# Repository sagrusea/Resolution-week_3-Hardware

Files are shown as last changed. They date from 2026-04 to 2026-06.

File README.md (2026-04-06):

# Resolution-week_3-Hardware
A cross made up of 16 leds with another 4 leds, one for each corner. I made this becouse i wanted to use the cd4020 and lm556 for the first time, and also create a good looking circuit.

#### Render:
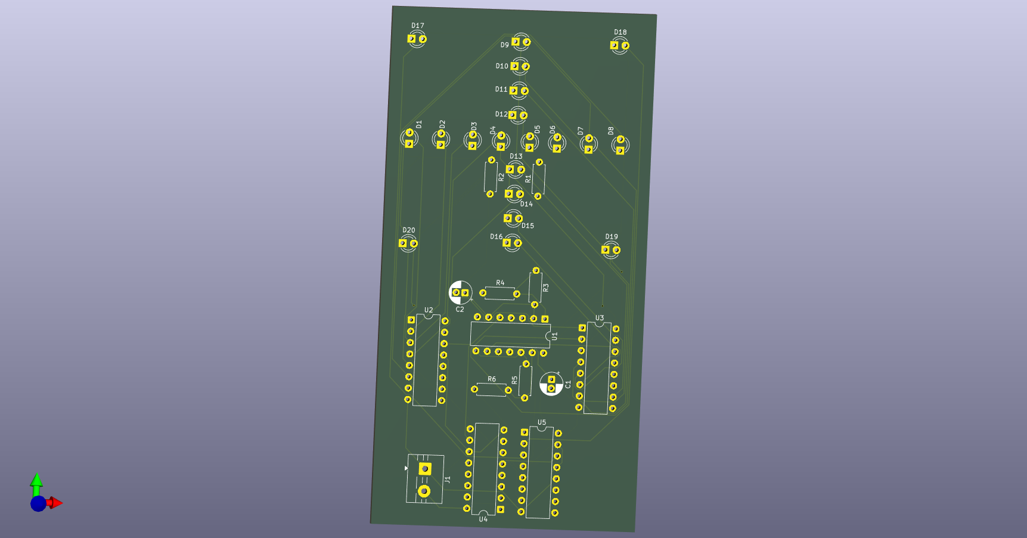
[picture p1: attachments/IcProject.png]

#### Schematic:
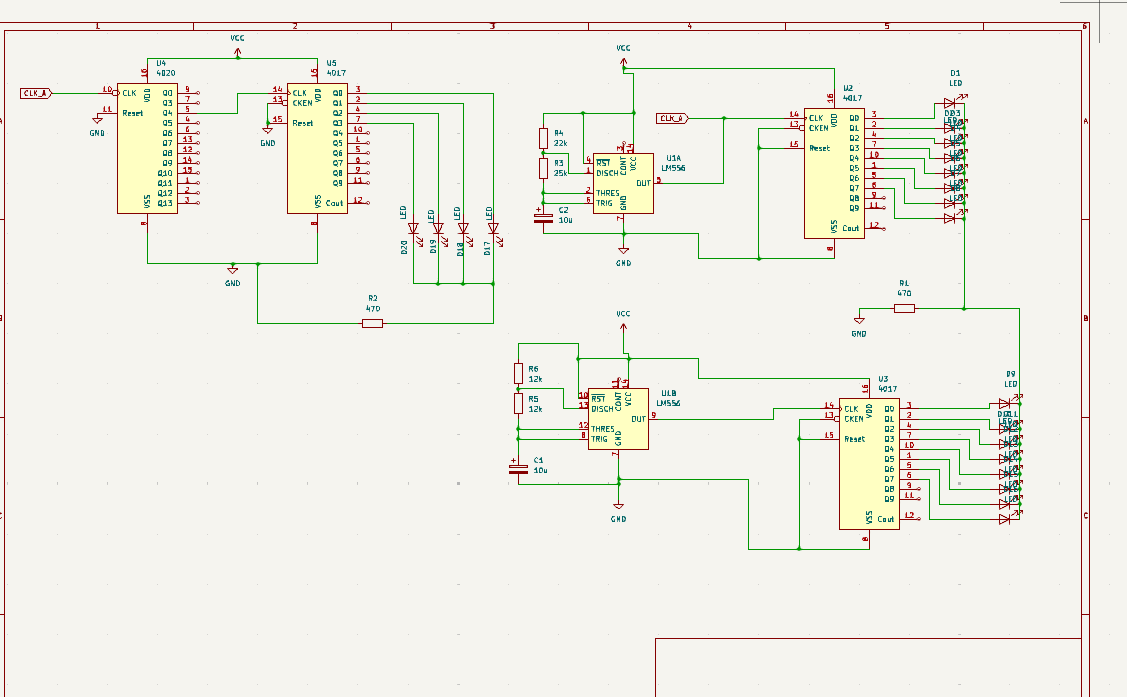
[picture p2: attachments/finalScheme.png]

#### KiCanvas:  
<a href="https://kicanvas.org/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">link</a>

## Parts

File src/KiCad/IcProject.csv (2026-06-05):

Reference | Qty | Value | DNP | Exclude from BOM | Exclude from Board | Footprint | Datasheet
C1,C2 | 2 | 10u |  |  |  | Capacitor_THT:CP_Radial_D5.0mm_P2.00mm
D1,D2,D3,D4,D5,D6,D7,D8,D9,D10,D11,D12,D13,D14,D15,D16 | 16 | LED |  |  |  | LED_THT:LED_D3.0mm
D17,D18,D19,D20 | 4 | Blue |  |  |  | LED_THT:LED_D3.0mm
J1 | 1 | Screw_Terminal_01x02 |  |  |  | TerminalBlock:TerminalBlock_MaiXu_MX126-5.0-02P_1x02_P5.00mm
R1 | 1 | 470 |  |  |  | Resistor_THT:R_Axial_DIN0207_L6.3mm_D2.5mm_P7.62mm_Horizontal
R2 | 1 | 220 |  |  |  | Resistor_THT:R_Axial_DIN0207_L6.3mm_D2.5mm_P7.62mm_Horizontal
R3 | 1 | 25k |  |  |  | Resistor_THT:R_Axial_DIN0207_L6.3mm_D2.5mm_P7.62mm_Horizontal
R4 | 1 | 22k |  |  |  | Resistor_THT:R_Axial_DIN0207_L6.3mm_D2.5mm_P7.62mm_Horizontal
R5,R6 | 2 | 12k |  |  |  | Resistor_THT:R_Axial_DIN0207_L6.3mm_D2.5mm_P7.62mm_Horizontal
U1 | 1 | LM556 |  |  |  | Package_DIP:DIP-14_W7.62mm | https://www.mouser.com/datasheet/2/405/lm556-405954.pdf
U2,U3,U5 | 3 | 4017 |  |  |  | Package_DIP:DIP-16_W7.62mm | http://www.intersil.com/content/dam/Intersil/documents/cd40/cd4017bms-22bms.pdf
U4 | 1 | 4020 |  |  |  | Package_DIP:DIP-16_W7.62mm | http://www.intersil.com/content/dam/Intersil/documents/cd40/cd4020bms-24bms-40bms.pdf

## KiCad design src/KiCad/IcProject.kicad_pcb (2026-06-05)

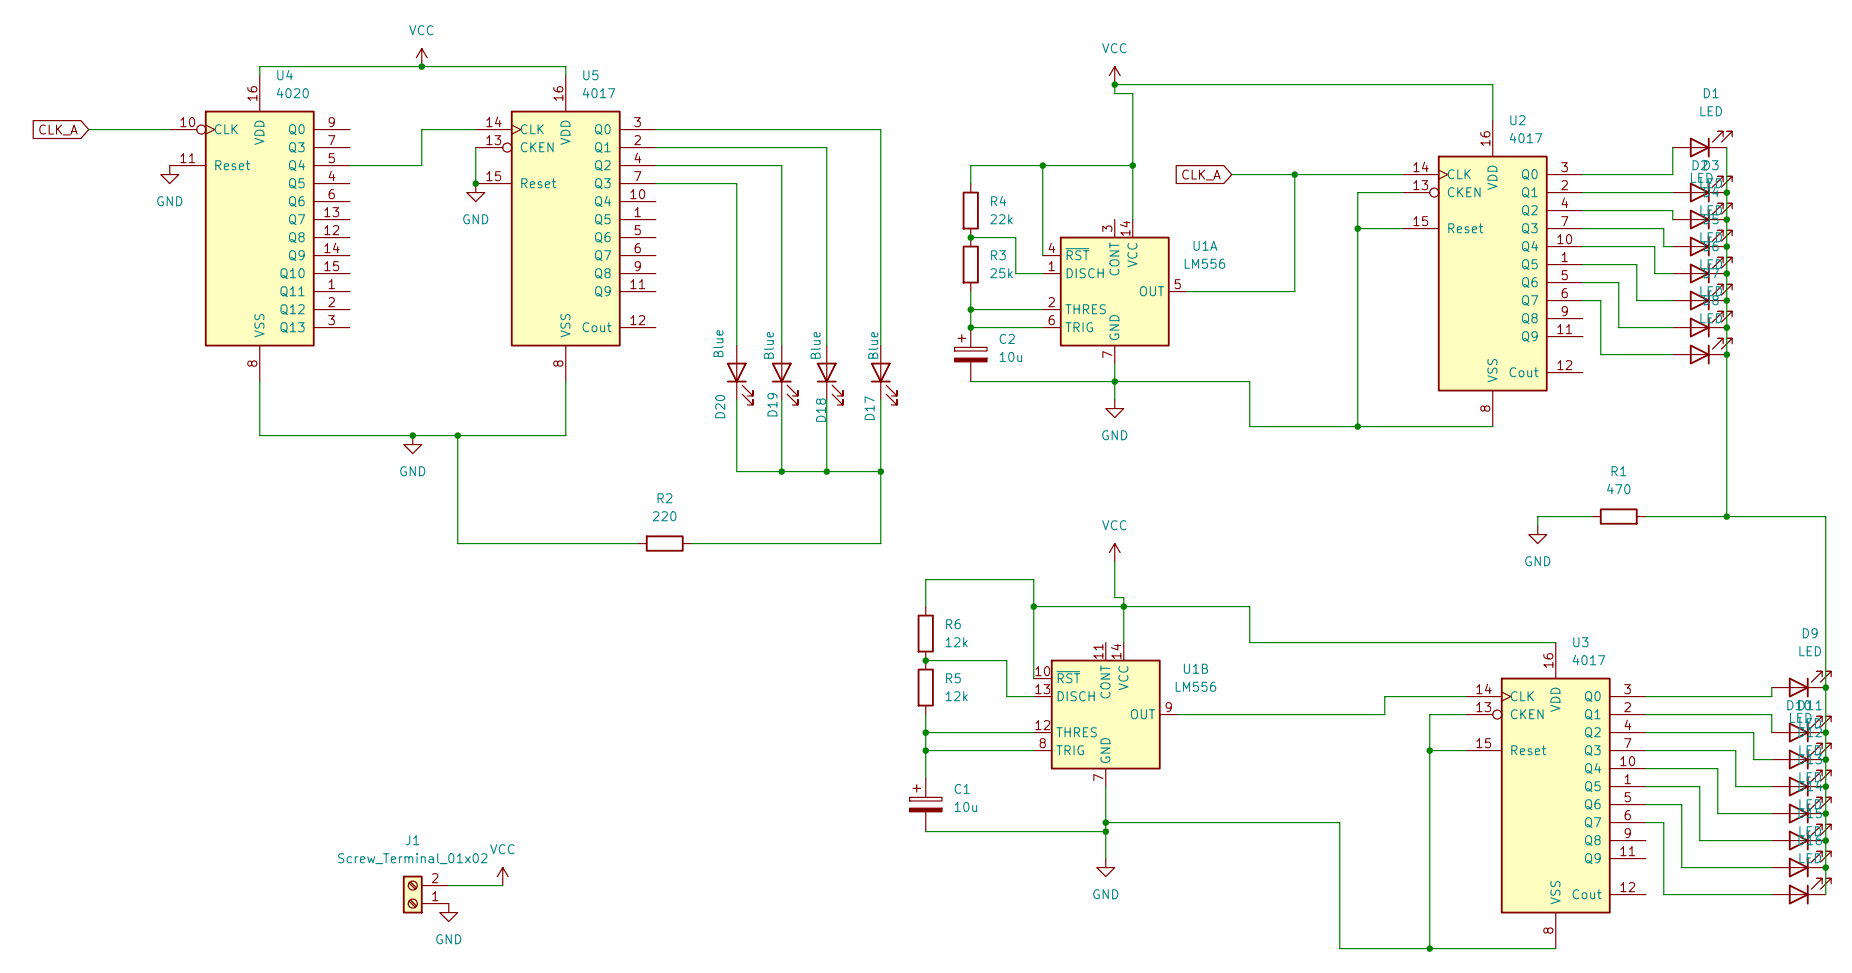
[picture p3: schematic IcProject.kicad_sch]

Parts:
C1, C2: 10u; CP_Radial_D5.0mm_P2.00mm
D1, D2, D3, D4, D5, D6, D7, D8, D9, D10, D11, D12, D13, D14, D15, D16: LED; LED_D3.0mm
D17, D18, D19, D20: Blue; LED_D3.0mm
J1: Screw_Terminal_01x02; TerminalBlock_MaiXu_MX126-5.0-02P_1x02_P5.00mm
R1: 470; R_Axial_DIN0207_L6.3mm_D2.5mm_P7.62mm_Horizontal
R2: 220; R_Axial_DIN0207_L6.3mm_D2.5mm_P7.62mm_Horizontal
R3: 25k; R_Axial_DIN0207_L6.3mm_D2.5mm_P7.62mm_Horizontal
R4: 22k; R_Axial_DIN0207_L6.3mm_D2.5mm_P7.62mm_Horizontal
R5, R6: 12k; R_Axial_DIN0207_L6.3mm_D2.5mm_P7.62mm_Horizontal
U1: LM556; DIP-14_W7.62mm
U2, U3, U5: 4017; DIP-16_W7.62mm
U4: 4020; DIP-16_W7.62mm

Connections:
CLK_A: U1.5 (OUT), U2.14 (CLK), U4.10 (CLK)
GND: C1.2, C2.2, J1.1, R1.1, R2.2, U1.7 (GND), U2.8 (VSS), U2.13 (CKEN), U2.15 (Reset), U3.8 (VSS), U3.13 (CKEN), U3.15 (Reset), U4.8 (VSS), U4.11 (Reset), U5.8 (VSS), U5.13 (CKEN), U5.15 (Reset)
unnamed: D1.2 (A), U2.3 (Q0)
unnamed: D1.1 (K), D2.1 (K), D3.1 (K), D4.1 (K), D5.1 (K), D6.1 (K), D7.1 (K), D8.1 (K), D9.1 (K), D10.1 (K), D11.1 (K), D12.1 (K), D13.1 (K), D14.1 (K), D15.1 (K), D16.1 (K), R1.2
unnamed: D2.2 (A), U2.2 (Q1)
unnamed: D3.2 (A), U2.4 (Q2)
unnamed: D4.2 (A), U2.7 (Q3)
unnamed: D5.2 (A), U2.10 (Q4)
unnamed: D6.2 (A), U2.1 (Q5)
unnamed: D7.2 (A), U2.5 (Q6)
unnamed: D8.2 (A), U2.6 (Q7)
unnamed: D9.2 (A), U3.3 (Q0)
unnamed: D10.2 (A), U3.2 (Q1)
unnamed: D11.2 (A), U3.4 (Q2)
unnamed: D12.2 (A), U3.7 (Q3)
unnamed: D13.2 (A), U3.10 (Q4)
unnamed: D14.2 (A), U3.1 (Q5)
unnamed: D15.2 (A), U3.5 (Q6)
unnamed: D16.2 (A), U3.6 (Q7)
unnamed: D17.2 (A), U5.3 (Q0)
unnamed: D17.1 (K), D18.1 (K), D19.1 (K), D20.1 (K), R2.1
unnamed: D18.2 (A), U5.2 (Q1)
unnamed: D19.2 (A), U5.4 (Q2)
unnamed: D20.2 (A), U5.7 (Q3)
unnamed: R3.1, R4.2, U1.1 (DISCH)
unnamed: C2.1, R3.2, U1.2 (THRES), U1.6 (TRIG)
unnamed: R5.1, R6.2, U1.13 (DISCH)
unnamed: U1.9 (OUT), U3.14 (CLK)
unnamed: C1.1, R5.2, U1.8 (TRIG), U1.12 (THRES)
unnamed: U4.5 (Q4), U5.14 (CLK)
VCC: J1.2, R4.1, R6.1, U1.4 (~RST), U1.10 (~RST), U1.14 (VCC), U2.16 (VDD), U3.16 (VDD), U4.16 (VDD), U5.16 (VDD)

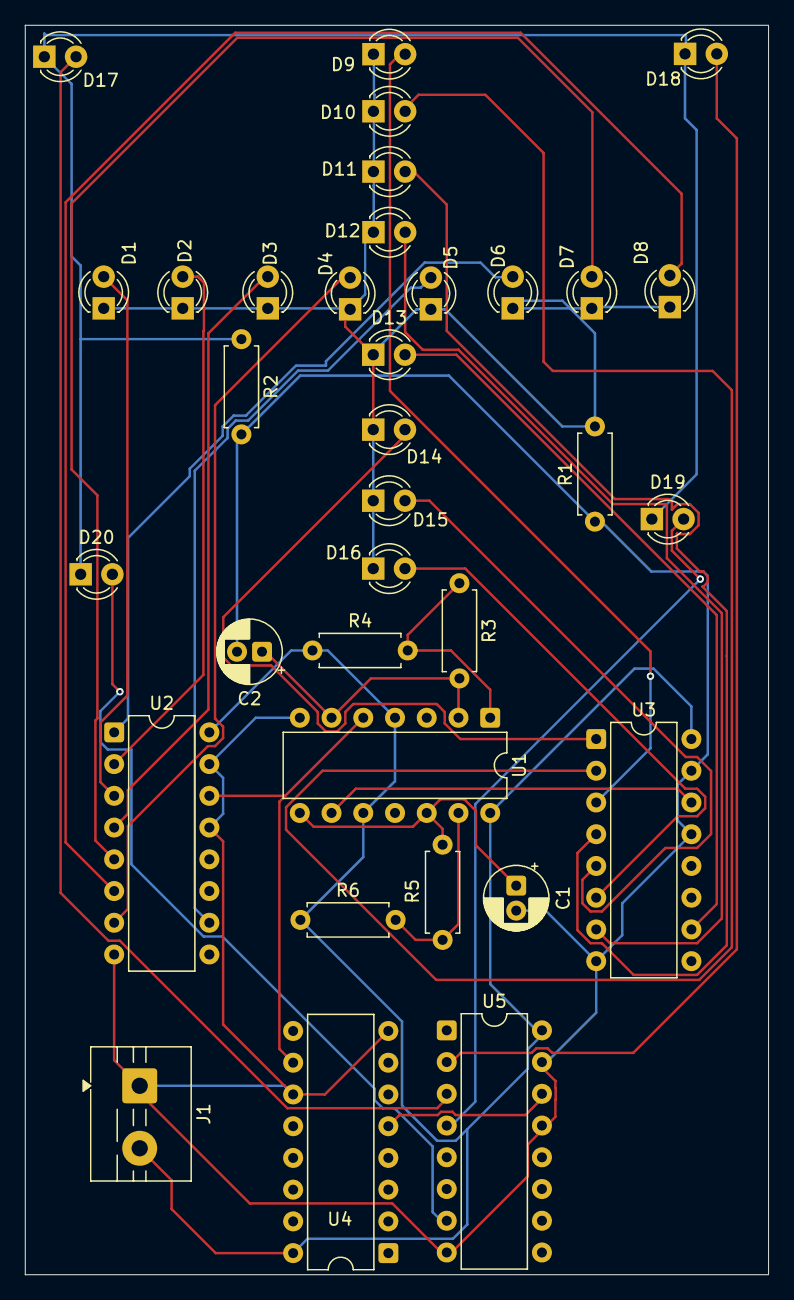
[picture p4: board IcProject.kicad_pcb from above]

Board: 2 copper layers, 59.5 x 100.0 mm, 34 parts (0 on the bottom side), 31 nets.

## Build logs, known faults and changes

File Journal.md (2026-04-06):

## 1.4.2026
### Time spent: 1h
i wanted to make a row of leds going from 1 to x and from x to 1 and going at varying speeds that the ics would dictate. My first step was to try and simulate the ics in a software of some sort, well i spent an hour trying to get multiple diffrent simulators working. I tried to do it in falstad which would actually be possible but way too much work, so i tried the next best thing i could think of, kicad spice simulation. I tried to look up spice models of the cd4020 and cd4017 but i wasnt succesfull. So i tried asking ai to give me the spice models and yet again nothing, i did a lot of debugging since kicad always spat a lot of errors at me, i didnt understand a single error, after an hour i gave up..

## 2.4.2026
### Time spent: 20 mins
I scrapped my old idea and started working on a completly new one.Firstly i looked up what the lm556 is and how i could use it, its basically 2 ne555s in one package, so i based my idea on 2 main frequencies. A crosshair of 8 (16 total) Leds + 4 leds in the corners, with frequencies as in the image. Since we have the main part i picked 2 cd4017 to drive the 16 leds i didnt have to research anything since i used it before. I will also most likely use a cd4020 for frequency C, and i will most likely change the frequencies(probably b and c so the cd4020 can handle tha math)  

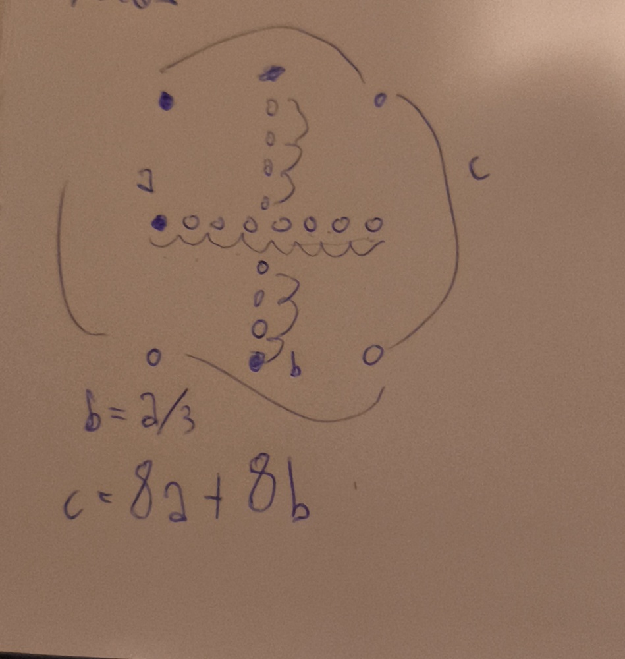
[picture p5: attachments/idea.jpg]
idea
  

> So far i have put the lm556 inside my kicad schematic, but its weird it is 2 symbols with either unit a or b markings. I also imported the cd4017 for both parts(a + b), and wired up the gnds and vccs, and outputs of both parts to their own cd4017  

## 2.4.2026 #2
### Time spent: 30 mins
I wired up the 2 cd4017s to the leds, and their reset and clk enable pins to GND. I connected the cathodes of the 16 leds to ground through a resistor(i will calculate the value later). I also added a cd4020 and another cd4017 to the schematic and wired the reset pins of both Ics to GND, and added a label for clock A and put the label to Lm556s part A and cd4020 clk so they are connected, i will need to do math to figure out the correct speed. Now a big thing i need to decide if i want the leds of the crosshair to go d1-d2........d8-d7-d6....  , or not. If i would choose the first option i would need to either lower the amount of leds to 6 so i could use the existing cd4017 or use an extra cd4017 but i dont think that would be efficient enough idk tho. That decision is for after i wake up since its a bit past midnight already.
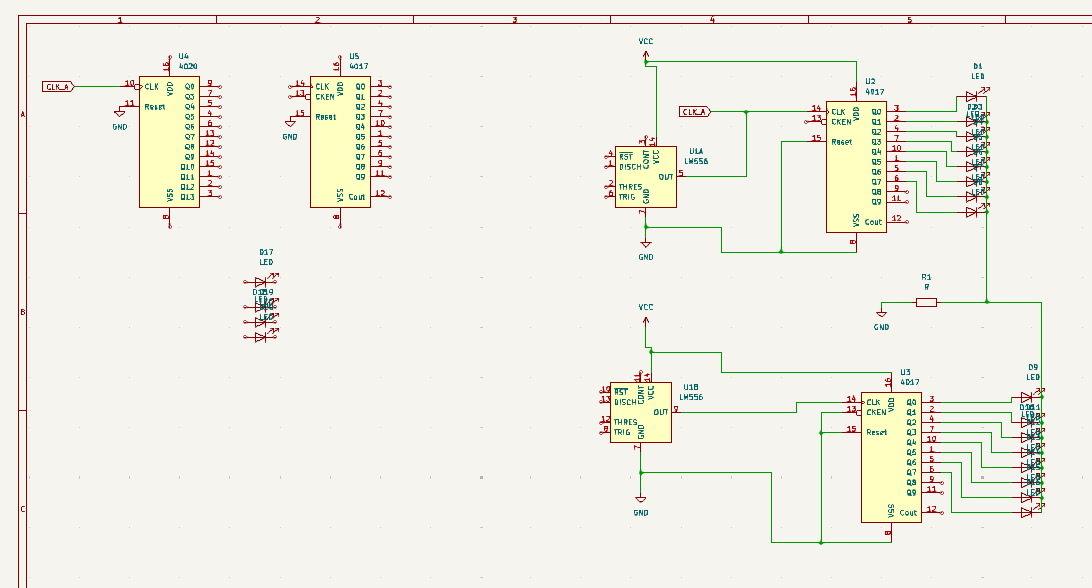
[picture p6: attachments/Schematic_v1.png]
  

## 6.4.2026
### Time spent: 1H 40 mins
From last time a lot changed i reworked the frequencies so frequencies ended up like this a = 2 Hz b = 4 Hz and c = a/8.  
> so c = 0.25Hz  

Than i used a NE555 calculator in astable configuration and calculated what resistors and capacitors i need for the frequencies a and b. I also decided that the 4 LEDs that are driven by frequency c will be blue so it has a nice contrast. Once i had my new version in mind i put all of the resistors in the config that the digikey calculator showed me. SO i added all of the polarised Caps and resistors according to my calculations. Wired it all up and i had my finished schematic.
final version of the scheme

Now that i had my schematic came the harder part making the PCB. But first i had to pick the footprints, which i somewhat followed the guide and somewhat just picked what looked best and would work. After i selected all of my footprints i imported the components from the schematic and started doing the layout that will be simmilar to the sketch. So i positioned the LEDs in a cross with the 4 blue LEDs in the corners, then I placed the Ics in a way i thought would be the best for routing, then i moved the parts that were needed for the ics or leds to work/not burn up. Once that was done i started by routing on the front layer, i routed all signals and and ic outpust, pretty much anything that wasnt vcc or gnd, along the way i had to use a few vias and route some parts on the back layer. Once that was done i routed the VCC and GND on the back layer occasionally using the front.
#### Finished PCB  

Finished PCB  

> i dont have the 3d models since they take up a lot of space.
